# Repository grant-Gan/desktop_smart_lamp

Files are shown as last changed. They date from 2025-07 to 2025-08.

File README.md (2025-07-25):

# Sunlike 护眼台灯

使用首尔半导体Sunlike灯珠开发了一款具有无线控制和滑动控制双交互模式的台灯，结构灵活，可根据实际使用环境灵活调节灯管结构。控制器基于ESP32-C2模组，采用Arduino框架进行开发。  
版权说明：本项目允许用户查看、使用、修改源代码。禁止将项目或其衍生作品用于商业目的（例如：销售、作为商业服务的一部分盈利）。用户在使用或分发（包括修改版）时，必须保留原始版权和许可声明（注明出处）

<!-- PROJECT SHIELDS -->

[][contributors-url]
[][forks-url]
[][stars-url]
[][issues-url]
[][license-url]
[][linkedin-url]

<!-- PROJECT LOGO -->
<br />

<p align="center">
  <a href="https://github.com/grant-Gan/desktop_smart_lamp/">
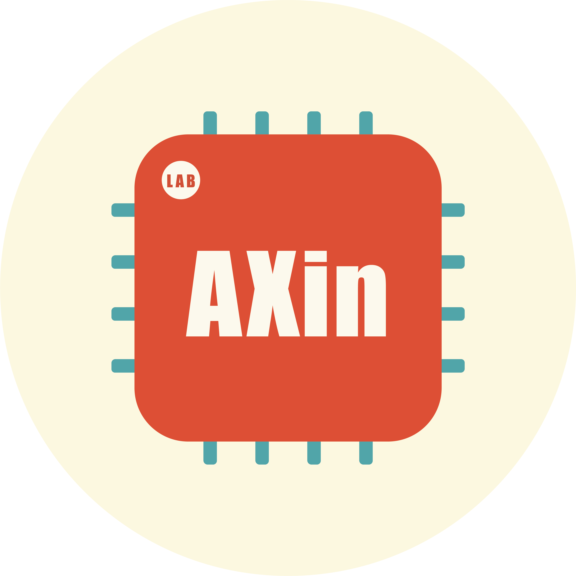
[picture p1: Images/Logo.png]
    
  </a>
  <h3 align="center">AXin实验室</h3>
  <p align="center">
    生命不息，折腾不止，Axin致力于DIY想要又买不起的产品~
    <br />
    <a href="https://github.com/grant-Gan/desktop_smart_lamp"><strong>探索本项目的文档 »</strong></a>
    <br />
    <br />
    <a href="https://github.com/grant-Gan/desktop_smart_lamp">查看Demo</a>
    ·
    <a href="https://github.com/grant-Gan/desktop_smart_lamp/issues">报告Bug</a>
    ·
    <a href="https://github.com/grant-Gan/desktop_smart_lamp/issues">提出新特性</a>
  </p>

</p>

## 目录

- [重点提示](#重点提示)
- [下载步骤](#下载步骤)
- [文件目录说明](#文件目录说明)
- [使用的框架](#使用的框架)
- [依赖库](#依赖库)
- [版本控制](#版本控制)
- [零件选型](#零件选型)
    1. [电源适配器](#电源适配器)
    2. [数据线](#数据线)
    3. [灯管](#灯管)
    4. [角码](#角码)
    5. [悬臂支架](#悬臂支架)
    6. [其它](#其它)
- [PCB焊接](#PCB焊接)
    1. [无线控制版本](#无线控制版本)
    2. [滑动控制版本](#滑动控制版本)
- [作者](#作者)
- [版权说明](#版权说明)

### 重点提示

截至到目前，台灯的旋转控制器代码仍然有Bug，AXin正在利用业余时间修复中，只能保证基础功能的正常使用。建议大家优先复刻滑动控制版本。

待开发功能：
1. 控制器Deep Sleep模式修复
2. 控制器与驱动板自动配对
3. 控制器低电提醒
4. HomeAssistant接入

### 下载步骤
Clone the repo

```sh
git clone https://github.com/grant-Gan/desktop_smart_lamp.git
```

### 文件目录说明

```
desktop_smart_lamp 
├── README.md
├── LICENSE
├── /3D_Model
│  ├── /Lamp_case
│  ├── /Rotary_Controller
│  ├── /Slider_Controller
├── /BOM
│  ├── /BOM_Base_Board_2025-07-23.xlsx
│  ├── /BOM_Driver Board _2025-07-23.xlsx
│  ├── /BOM_Rotary_Controller_Board_2025-07-23.xlsx
│  ├── /BOM_Slider_Controller_Board_2025-07-23.xlsx
├── /images
├── /Code
│  ├── /Lamp_Driver
│  ├── /Lamp_Driver
├── /PCBA
│  ├── /Gerber_Base_Board_20250723.zip
│  ├── /Gerber_Driver_Board_20250723.zip
│  ├── /Gerber_Rotary_Controller_Board_20250723.zip
│  ├── /Gerber_Slider_Controller_Board_20250723.zip
├── /Schematic
│  ├── /Base_board.pdf
│  ├── /Driver_board.pdf
│  ├── /Rotary_Controller_Board.pdf
│  ├── /Slider_Controller_board.pdf

```

### 使用的框架
[esp-idf](https://github.com/espressif/esp-idf) 

### 依赖库

- [arduino-esp32](https://github.com/espressif/arduino-esp32)
- [Button2](https://github.com/LennartHennigs/Button2)
- [ai-esp32-rotary-encoder](https://github.com/igorantolic/ai-esp32-rotary-encoder)

### 版本控制

该项目使用Git进行版本管理。您可以在repository参看当前可用版本。

### 零件选型
#### 电源适配器
本项目设计最大功耗为30W，输入电压为12~20V，20V时效率比较高，驱动板发热下降，推荐首选。因此需要使用额定30W以上、支持20V输出、支持PD充电协议的电源适配器，大部分手机配的快充头，如果功率大于30W，有TYPE-C接口都可以使用，不必额外购买。
<p align="center">
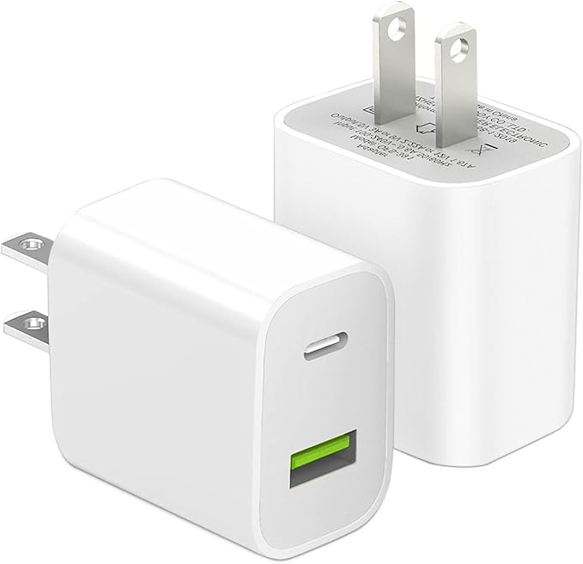
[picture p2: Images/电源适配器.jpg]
    
  <p align="center">有Type-C输出的电源适配器，通常支持PD协议</p>
</p>

#### 数据线
本项目使用的时C2C快充数据线，建议额定功率60W以上，长度根据使用环境选择，AXin使用的是2米的数据线，能够匹配大部分使用场景。
<p align="center">
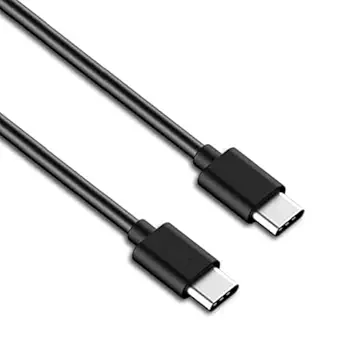
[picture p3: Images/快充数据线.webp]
    
  <p align="center">C2C快充数据线</p>
</p>

#### 灯管
本项目使用70cm长，横截面宽26mm，高11mm的铝合金灯管，购买地址见B站视频。商家默认出售的是1米长度，请留言需要裁剪。

#### 角码
本项目使用的是20*32*60的L型不锈钢角码，若想选用其他型号，需要保证螺丝孔开口大于6.0mm以上，能够让悬臂支架上1/4螺丝头伸进去。
<p align="center">
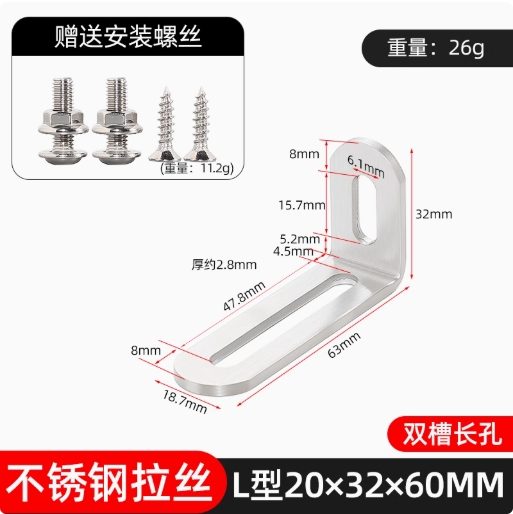
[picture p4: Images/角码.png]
    
  <p align="center">20x32x60角码</p>
</p>

#### 悬臂支架
本项目使用的是带有1/4螺丝的悬臂支架配合铝制夹具，需要注意的是由于灯管比较长，力臂较大，一定要选择质量足够好的悬臂支架才行，不然固定扳手的螺母会滑丝，建议大家不要贪图便宜，在正规渠道购买。
<p align="center">
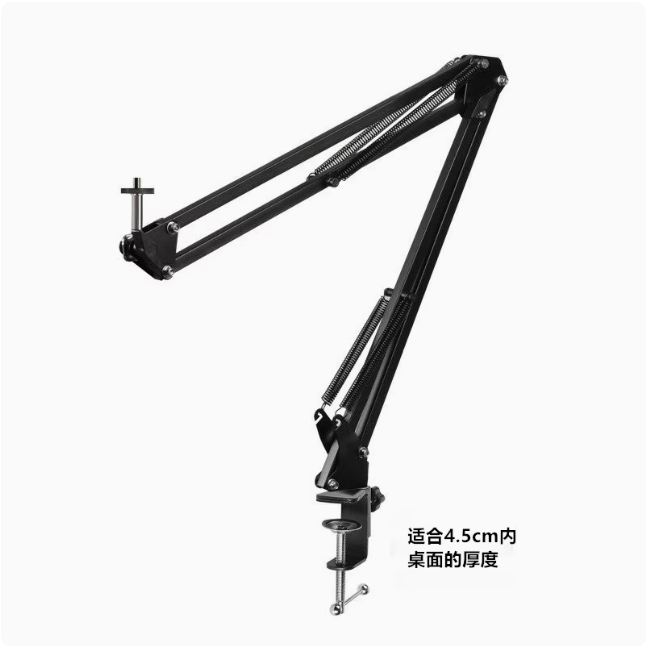
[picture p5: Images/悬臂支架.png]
    
  <p align="center">带1/4螺丝的悬臂支架</p>
</p>

#### 螺丝
- 无线控制版   

| 位置 | 型号 | 类型 | 螺丝头类型 | 数量 |
|---|---|---|---|----|
| 堵头与灯管连接 | M2.6*20 | 自攻螺丝 | 内六角 | 4  |
| 堵头上下连接  | M2*12 | 普通螺丝 | 内六角 | 2  |
| 堵头上下连接  | M2 | 螺母 | \ | 2  |
| 控制器 | M2*12 | 自攻螺丝 | 内六角 | 5  |
| 灯管与L角码连接 | M6*6 | 普通螺丝 | 内六角 | 2  |
| 灯管与L角码连接 | M6*10*2 | 方形螺母 | \ | 2  |
| L角码与支架连接 | 1/4-20牙 | 防滑螺母 | \ | 1  |
| L角码与支架连接 | M6*10*2 | 垫片 | \ | 1  |

- 滑动控制版

| 位置 | 型号 | 类型 | 螺丝头类型 | 数量 |
|---|---|---|---|----|
| 堵头与灯管连接  | M2.6*20 | 自攻螺丝 | 内六角 | 4  |
| 堵头与控制器连接 | M2*25 | 普通螺丝 | 内六角 | 2  |
| 堵头上下连接 | M2 | 螺母 | \ | 2  |
| 控制器与灯管连接 | M2*18 | 自攻螺丝 | 内六角 | 2  |
| 灯管与L角码连接 | M6*6 | 普通螺丝 | 内六角 | 2  |
| 灯管与L角码连接 | M6*10*2 | 方形螺母 | \ | 2  |
| L角码与支架连接 | 1/4-20牙 | 防滑螺母 | \ | 1  |
| L角码与支架连接 | M6*10*2 | 垫片 | \ | 1  |

#### 其它
其它零件暂时没有需要重点注意的，想起来或者等到后续问的朋友比较多再行补充~

### PCB焊接

#### 无线控制版本
- 驱动板  
无线控制驱动板使用ESP32-C2模组，使用PWM调光，驱动芯片为LGS63042EP,中间部分仅需要焊接R9、R18两个下拉电阻及D5、D6两个稳压二极管，其中稳压二极管用于保护驱动芯片EN引脚，可选。  
**注意事项：驱动端输出电压较高，需使用50V以上电容。**
<p align="center">
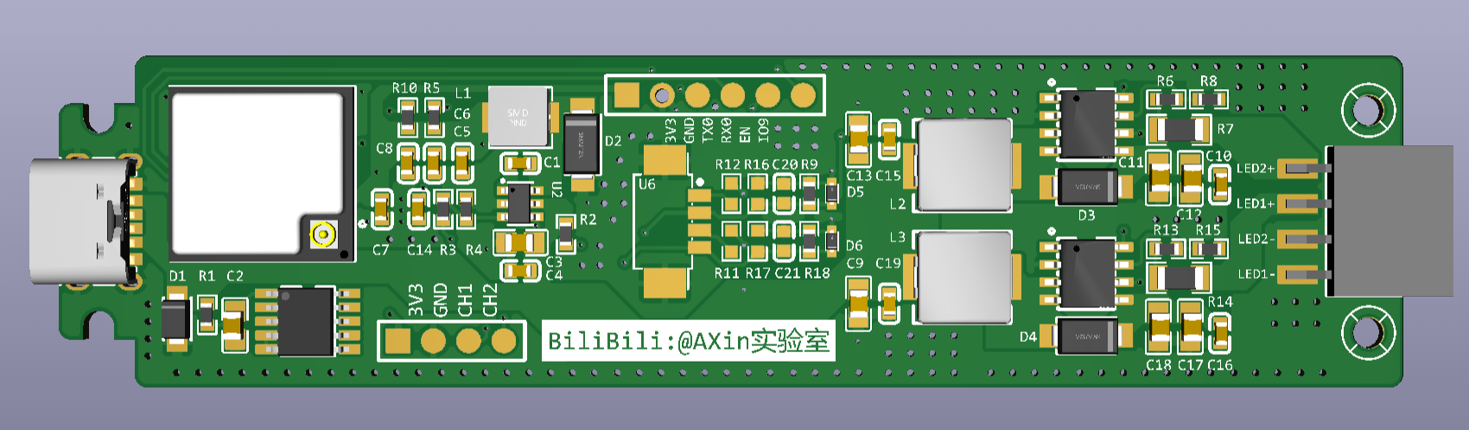
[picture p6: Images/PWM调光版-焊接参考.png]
    
无线控制版驱动板焊接参考 
</p>
  
- 控制板   
**注意事项：控制器焊接需要留意编码器的选型，本项目采用的编码器型号为EC11、手柄长度12mm、梅花柄、正码（顺时针）、旋转一圈脉冲20位**

<p align="center">
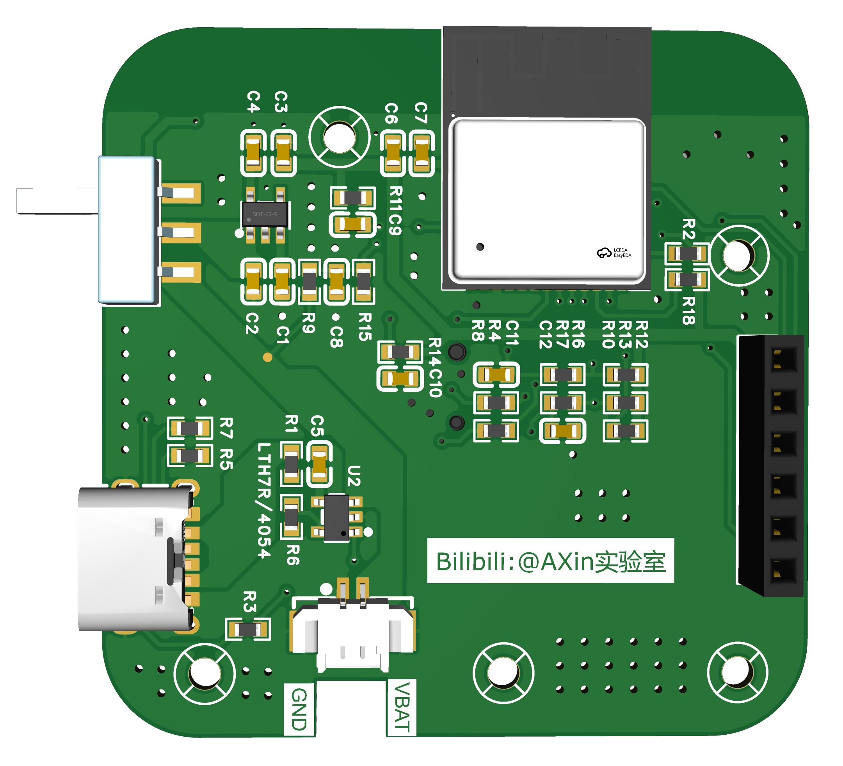
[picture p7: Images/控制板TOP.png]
  
  <p align="center">控制器焊接参考</p>
</p>

<p align="center">
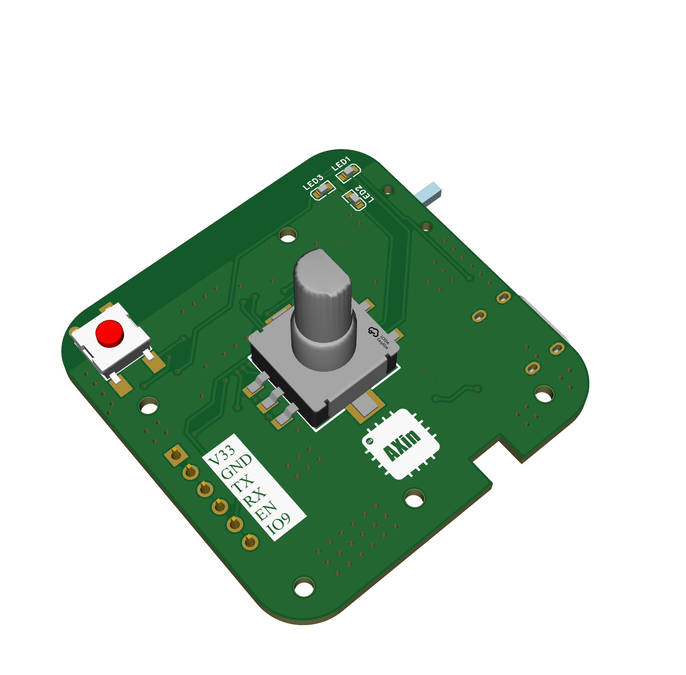
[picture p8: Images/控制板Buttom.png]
  
  <p align="center">控制器焊接参考</p>
</p>

#### 滑动控制版本
- 驱动板  
滑动控制版本可以不焊接控制器、DCDC部分的元器件，成本低不少，若没有无线控制需求，推荐给大家优先尝试。具体需要焊接的元件请参考下方的焊接参考图和原理图。
**注意事项：驱动端输出电压较高，需使用50V以上电容。**
<p align="center">
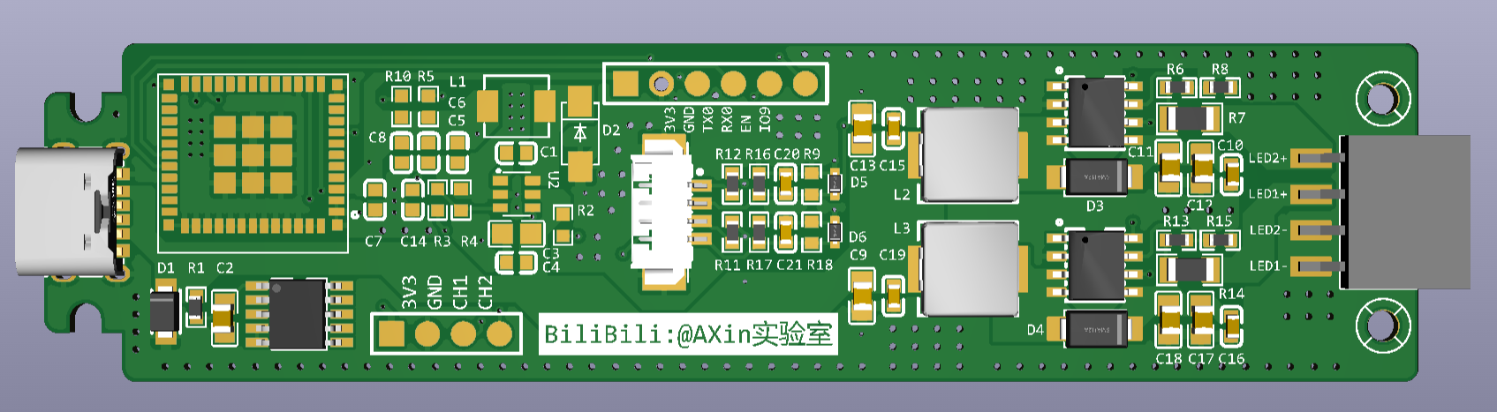
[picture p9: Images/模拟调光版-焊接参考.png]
    
滑动控制版驱动板焊接参考 
</p>  

- 滑动控制板  
这里没什么好说的，直接按照图焊接好就行。
<p align="center">
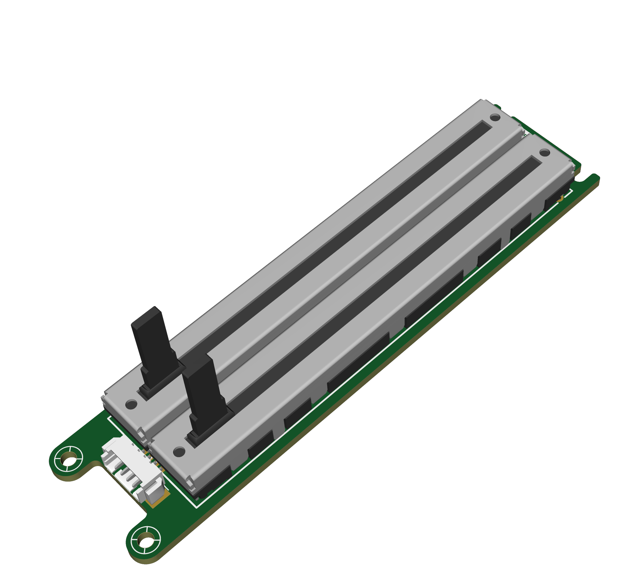
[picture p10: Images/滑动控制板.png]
    
  <p align="center">滑动控制板</p>
</p>  

### 作者

AXin实验室

Bilibili:@AXin实验室 小红书:@AXin实验室   

### 版权说明
本项目采用 **Creative Commons Attribution-NonCommercial-ShareAlike 4.0 International License** 授权。
您可自由地：
*   **共享** — 在任何媒介以任何形式复制、发行本作品
*   **演绎** — 修改、转换或以本作品为基础进行创作

惟须遵守以下条件：
*   **署名** — 您必须给出[适当的署名](https://creativecommons.org/licenses/by-nc-sa/4.0/deed.zh)，提供指向本许可协议的链接，同时标明是否（对原始作品）作了修改。您可以用任何合理的方式来署名，但不得以任何方式暗示许可人为您或您的使用背书。
*   **非商业性使用** — 您不得将本作品用于商业目的。
*   **相同方式共享** — 如果您再混合、转换或者基于本作品进行创作，您必须基于[与原先许可协议相同的许可协议](https://creativecommons.org/licenses/by-nc-sa/4.0/deed.zh) 分发您贡献的作品。

完整的许可条款请见：[LICENSE](LICENSE) 文件。

该项目签署了MIT 授权许可，详情请参阅 [LICENSE.txt](https://github.com/grant-Gan/desktop_smart_lamp/LICENSE.txt)

<!-- links -->
[your-project-path]:grant-Gan/desktop_smart_lamp
[contributors-shield]: https://img.shields.io/github/contributors/grant-Gan/desktop_smart_lamp.svg?style=flat-square
[contributors-url]: https://github.com/grant-Gan/desktop_smart_lamp/graphs/contributors
[forks-shield]: https://img.shields.io/github/forks/grant-Gan/desktop_smart_lamp.svg?style=flat-square
[forks-url]: https://github.com/grant-Gan/desktop_smart_lamp/network/members
[stars-shield]: https://img.shields.io/github/stars/grant-Gan/desktop_smart_lamp.svg?style=flat-square
[stars-url]: https://github.com/grant-Gan/desktop_smart_lamp/stargazers
[issues-shield]: https://img.shields.io/github/issues/grant-Gan/desktop_smart_lamp.svg?style=flat-square
[issues-url]: https://img.shields.io/github/issues/grant-Gan/desktop_smart_lamp.svg
[license-shield]: https://img.shields.io/github/license/grant-Gan/desktop_smart_lamp.svg?style=flat-square
[license-url]: https://github.com/grant-Gan/desktop_smart_lamp/blob/master/LICENSE.txt
[linkedin-shield]: https://img.shields.io/badge/-LinkedIn-black.svg?style=flat-square&logo=linkedin&colorB=555
[linkedin-url]: https://www.bilibili.com/video/BV1rygnzuE4w

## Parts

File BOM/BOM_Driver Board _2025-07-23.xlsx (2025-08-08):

No. | Manufacturer Part | Primary Category | Secondary Category | Manufacturer | LCSC Part Name | Footprint | Value | Designator | Quantity | Supplier Part
1 | CC0603KRX7R9BB104 |  |  | YAGEO(国巨) | 100nF ±10% 50V | C0603 | 100nF | C1,C4,C6,C8,C10,C13,C16,C19 | 8 | C14663
2 | HGC0805R5106K500NSLJ | 电容 | 贴片电容(MLCC) | Chinocera(华瓷) | 10uF ±10% 50V | C0805 | 10uF | C2,C3,C9,C11,C12,C15,C17,C18 | 8 | C22367830
3 | CGA0603X5R106K100JT |  |  | HRE(芯声) | 10uF ±10% 10V | C0603 | 10uF | C5,C7,C20,C21 | 4 | C6119842
4 | CGA0603X5R105K500JT |  |  | HRE(芯声) | 1uF ±10% 50V | C0603 | 1uF | C14 | 1 | C6119852
5 | SMF20A |  |  | 宏嘉诚 | SMF20A | SOD-123FL_L2.8-W1.9-LS3.7-RD |  | D1 | 1 | C41411782
6 | SS34 | 二极管 | 肖特基二极管 | 宏迦橙 | 电压:40V 电流:3A,电压:60V 电流:3A | SMA_L4.3-W2.6-LS5.0-FD |  | D2 | 3 | C7420365
6 | SS34,SS36 | 二极管 | 肖特基二极管 | 宏迦橙 | 电压:60V 电流:3A,电压:60V 电流:3A | SMA_L4.3-W2.6-LS5.0-FD |  | D3,D4 | 3 | C7420367
7 | BZX584C5V1 |  |  | 宏迦橙 | BZX584C5V1 | SOD-523_L1.2-W0.8-LS1.6-FD |  | D5,D6 | 2 | C19077463
8 | FXL0420-100-M |  |  | cjiang(长江微电) | 10uH ±20% 2.2A | IND-SMD_L4.4-W4.2 | 10uH | L1 | 1 | C177242
9 | FXL0630-4R7-M |  |  | cjiang(长江微电) | 4.7uH ±20% 9A | IND-SMD_L7.0-W6.6 | 4.7uH | L2,L3 | 2 | C167220
10 |  | Connector | 2.54mm |  |  | 卧贴排母 2.54mm 4P |  | P1 | 1
11 | 0603WAJ0102T5E |  |  | UNI-ROYAL(厚声) | 1kΩ ±5% 100mW 厚膜电阻 | R0603 | 1kΩ | R1 | 1 | C25585
12 | 0603WAJ0103T5E |  |  | UNI-ROYAL(厚声) | 10kΩ ±5% 100mW 厚膜电阻 | R0603 | 10kΩ | R2,R5,R9,R10,R18 | 5 | C15401
13 | FRC0603F1302TS | 电阻 | 贴片电阻 | FOJAN(富捷) | 13kΩ ±1% 100mW 厚膜电阻 | R0603 | 13kΩ | R3 | 1 | C2906992
14 | FRC0603F4301TS | 电阻 | 贴片电阻 | FOJAN(富捷) | 4.3kΩ ±1% 100mW 厚膜电阻 | R0603 | 4.3kΩ | R4 | 1 | C2930099
15 | 0603WAF2003T5E |  |  | UNI-ROYAL(厚声) | 200kΩ ±1% 100mW 厚膜电阻 | R0603 | 200kΩ | R6,R13 | 2 | C25811
16 | 1206W4F500LT5E |  |  | UNI-ROYAL(厚声) | 500mΩ ±1% 250mW 厚膜电阻 | R1206 | 500mΩ | R7,R14 | 2 | C25340
17 | RC0603FR-074K7L |  |  | YAGEO(国巨) | 厚膜电阻 4.7kΩ ±1% 100mW | R0603 | 4.7kΩ | R8,R15 | 2 | C99782
18 | 0603WAF9101T5E |  |  | UNI-ROYAL(厚声) | 9.1kΩ ±1% 100mW 厚膜电阻 | R0603 | 9.1kΩ | R11,R12 | 2 | C23260
19 | 0603WAF5100T5E |  |  | UNI-ROYAL(厚声) | 510Ω ±1% 100mW 厚膜电阻 | R0603 | 510Ω | R16,R17 | 2 | C23193
20 |  |  |  |  |  | M2螺丝 |  | SCREW1,SCREW2 | 2
21 | CH224K | 通信接口芯片/UART/485/232 | USB芯片 | WCH(南京沁恒) | USB PD等多快充协议受电芯片CH224 | ESSOP-10_L4.9-W3.9-P1.0-LS6.0-TL-EP |  | U1 | 1 | C970725
22 | LGS5145 | 电源管理 | DC-DC电源芯片 | Legend-Si(棱晶半导体) | 高效率异步降压转换器 | SOT-23-6_L2.9-W1.7-P0.95-LS2.8-BL |  | U2 | 1 | C5123971
23 | ESP8684-MINI-1U-H4 | 物联网/通信模块 | 蓝牙模块 | ESPRESSIF(乐鑫) | ESP8684-MINI-1U-H4 | WIFIM-SMD_61P-L13.2-W12.5-P0.80 |  | U3 | 1 | C7497295
24 | LGS63042EP | 数码管驱动/LED驱动 | LED驱动 | Legend-Si(棱晶半导体) | 输出1.2A PWM调光 降压,升压型驱动 | ESOP-8_L4.9-W3.9-P1.27-LS6.0-TL-EP3.3 |  | U4,U5 | 2 | C5280696
25 | ZX-MX1.25-4PWT | 连接器 | 线对板针座 | Megastar(兆星) | 1x4P 间距:1.25mm 卧贴 系列:PicoBlade(MX 1.25) 配套胶壳型号：ZX-MX1.25-4PJK 配套端子型号：ZX-MX1.25-DZ 配套杜邦线型号：ZX-MX1.25-4PBXC | CONN-SMD_4P-P1.25-MX1.25-4P-WT |  | U6 | 1 | C7430470
26 | TYPE-C 6P(073) |  |  | SHOU HAN(首韩) | Type-C 母 卧贴 | TYPE-C-SMD_TYPE-C-6P-073 |  | USB1 | 1 | C668623

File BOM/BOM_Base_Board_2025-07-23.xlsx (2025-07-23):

No. | Manufacturer Part | Primary Category | Secondary Category | Manufacturer | Footprint | Value | Designator | Quantity
1 | STW9C2SB-S | 光电器件 | 发光二极管/LED | 首尔半导体 | LED-SMD_L3.0-W3.0_XL-3030UWC-1W-6V | 2700K, 6V, 1W, 150mA | LED7,LED8,LED9,LED10,LED11 | 5
1 | STW9C2SB-S | 光电器件 | 发光二极管/LED | 首尔半导体 | LED-SMD_L3.0-W3.0_XL-3030UWC-1W-6V | 5000K, 6V, 1W, 150mA | LED1,LED2,LED3,LED4,LED5 | 5
2 |  | Connector | 2.54mm |  | 卧贴排母 2.54mm 4P |  | P1 | 1
3 |  | Connector | 2.54mm |  | 卧贴排针 2.54mm 4P |  | P2 | 1

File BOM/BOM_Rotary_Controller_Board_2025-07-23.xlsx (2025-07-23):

No. | Manufacturer Part | Primary Category | Secondary Category | Manufacturer | LCSC Part Name | Footprint | Value | Designator | Quantity | Supplier Part
1 | CGA0603X5R106K100JT |  |  | HRE(芯声) | 10uF ±10% 10V | C0603 | 10uF | C1,C3,C5,C6,C9 | 5 | C6119842
2 | CGA0603X7R104K500JT |  |  | HRE(芯声) | 100nF ±10% 50V | C0603 | 100nF | C2,C4,C7,C8 | 4 | C6119867
3 | CC0603KRX7R9BB103 |  |  | YAGEO(国巨) | 10nF ±10% 50V | C0603 | 10nF | C10,C11,C12 | 3 | C100042
4 | 2.54-1*6P母 | 连接器 | 排母 | BOOMELE(博穆精密) |  | HDR-TH_6P-P2.54-V-F |  | H1 | 1 | C40877
5 | ME6211C33M5G-N | 电源管理 | 线性稳压器(LDO) | MICRONE(南京微盟) | 输入6V 输出3.3V 500mA | SOT-23-5_L3.0-W1.7-P0.95-LS2.8-BL |  | LDO1 | 1 | C82942
6 | XL-1608UWC-04 |  |  | XINGLIGHT(成兴光) | XL-1608UWC-04 | LED0603-RD_WHITE |  | LED1,LED2,LED3 | 3 | C965808
7 | FRL0603JR500TS |  |  | FOJAN(富捷) | 500mΩ ±5% 100mW 厚膜电阻 | R0603 | 500mΩ | R1 | 1 | C2930046
8 | 0603WAF4701T5E |  |  | UNI-ROYAL(厚声) | 4.7kΩ ±1% 100mW 厚膜电阻 | R0603 | 4.7kΩ | R2,R3,R4,R8 | 4 | C23162
9 | 0603WAF5101T5E |  |  | UNI-ROYAL(厚声) | 5.1kΩ ±1% 100mW 厚膜电阻 | R0603 | 5.1kΩ | R5,R7 | 2 | C23186
10 | 0603WAF2402T5E |  |  | UNI-ROYAL(厚声) | 24kΩ ±1% 100mW 厚膜电阻 | R0603 | 24kΩ | R6 | 1 | C23352
11 | 0603WAJ0102T5E |  |  | UNI-ROYAL(厚声) | 1kΩ ±5% 100mW 厚膜电阻 | R0603 | 1kΩ | R9 | 1 | C25585
12 | 0603WAJ0103T5E |  |  | UNI-ROYAL(厚声) | 10kΩ ±5% 100mW 厚膜电阻 | R0603 | 10kΩ | R10,R11,R12,R13,R14,R15,R16,R17,R18 | 9 | C15401
13 |  |  |  |  |  | M2螺丝 |  | SCREW1,SCREW2,SCREW3,SCREW4,SCREW5 | 5
14 | KH-6X6X7H-STM | 按键/开关 | 轻触开关 | kinghelm(金航标) | 6*6*7mm 立贴 轻触开关 | SW-SMD_4P-L6.0-W6.0-P4.50-LS9.0-2 |  | SW1 | 1 | C2837533
15 | EC11E09244BS | 按键/开关 | 旋转编码器 | ALPSALPINE(阿尔卑斯阿尔派) | EC11E09244BS | SW-SMD_EC11 |  | SW2 | 1 | C470742
16 |  |  |  |  |  | Test-Point-0.5mm |  | TP1 | 1
17 |  |  |  |  |  | MSKT-12D14 |  | U1 | 1
18 | LTH7R/4054 | 电源管理 | 电池管理 | FM(富满) | LTH7R/4054 | SOT-23-5_L2.9-W1.6-P0.95-LS2.8-BR |  | U2 | 1 | C2913899
19 | ZX-MX1.25-2PWT | 连接器 | 线对板针座 | Megastar(兆星) | 1x2P 间距:1.25mm 卧贴 系列:PicoBlade(MX 1.25) 配套胶壳型号：ZX-MX1.25-2PJK 配套端子型号：ZX-MX1.25-DZ 配套杜邦线型号：ZX-MX1.25-2PBXC | CONN-SMD_2P-P1.25_MEGASTAR_ZX-MX1.25-2PWT |  | U3 | 1 | C7430468
20 | ESP8684-MINI-1-H2 | 物联网/通信模块 | WiFi模块 | ESPRESSIF(乐鑫) | ESP8684-MINI-1-H2 | WIFI-SMD_ESP8684-MINI-1 |  | U4 | 1 | C3013915
21 | TYPE-C 6P(073) |  |  | SHOU HAN(首韩) | Type-C 母 卧贴 | TYPE-C-SMD_TYPE-C-6P_5 |  | USB1 | 1 | C668623

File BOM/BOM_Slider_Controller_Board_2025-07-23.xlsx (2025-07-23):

No. | Manufacturer Part | Primary Category | Secondary Category | Manufacturer | LCSC Part Name | Footprint | Value | Designator | Quantity | Supplier Part
1 | RS6011DP6003 | 电阻 | 可调电阻/电位器 | ALPSALPINE(阿尔卑斯阿尔派) | 10kΩ ±20%,20kΩ ±20% | RES-ADJ-TH_L75.0-W9.0_RS60112A6A0C | 10kΩ | R13,R14 | 2
2 |  |  |  |  |  | M2螺丝 |  | SCREW1,SCREW2,SCREW3,SCREW4 | 4
3 | ZX-MX1.25-4PWT | 连接器 | 线对板针座 | Megastar(兆星) | 1x4P 间距:1.25mm 卧贴 系列:PicoBlade(MX 1.25) 配套胶壳型号：ZX-MX1.25-4PJK 配套端子型号：ZX-MX1.25-DZ 配套杜邦线型号：ZX-MX1.25-4PBXC | CONN-SMD_4P-P1.25-MX1.25-4P-WT |  | U6 | 1 | C7430470

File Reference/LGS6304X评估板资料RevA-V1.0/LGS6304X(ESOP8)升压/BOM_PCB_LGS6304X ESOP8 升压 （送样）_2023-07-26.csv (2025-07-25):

ID | Name | Designator | Footprint | Quantity | Manufacturer Part | Manufacturer | Supplier | Supplier Part | Price
1 | 10uF | C3,C2 | C0805 | 2 | C1210C106K5RAC7800 | KEMET | LCSC | C141222 | 2.83
2 | TP1502 | EN,LED+,VIIN,GND | TEST POINT -2 | 4 | Header-Male-2.54_1x1 | ReliaPro | LCSC | C81276 | 0.0413
3 | 4.7uF | C1 | C1210 | 1 | C1210C106K5RAC7800 | KEMET | LCSC | C141222 | 2.83
4 | PMEG6020ER,115 | D1 | SOD-123_L2.8-W1.8-LS3.7-RD | 1 | PMEG6020ER,115 | Nexperia | LCSC | C98663 | 0.9184
5 | 1 | R6 | R0805 | 1 | 0805W8F100KT5E | UNI-ROYAL(厚声) | LCSC | C25271 | 0.0172
6 | 4.7uH | L1 | IND-SMD_L5.4-W5.2 | 1 | MWSA0503-100MT | Sunlord | LCSC | C139506 | 1.1875
7 | 470k | R3 | R0603 | 1 |  |  |  | C23178 | 0.0064
8 | 10k | R4,R1 | R0603 | 2 |  |  |  | C25804 | 0.0055
9 | 10K | R2 | R0603 | 1 |  |  |  | C13167 | 0.0064

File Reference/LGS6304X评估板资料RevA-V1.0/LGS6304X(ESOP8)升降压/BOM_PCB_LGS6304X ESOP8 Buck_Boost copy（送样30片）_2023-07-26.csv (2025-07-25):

ID | Name | Designator | Footprint | Quantity | Manufacturer Part | Manufacturer | Supplier | Supplier Part | Price
1 | 10uF | C2 | C0805 | 1 | C1210C106K5RAC7800 | KEMET | LCSC | C141222 | 2.83
2 | 10uF | C1 | C1210 | 1 | C1210C106K5RAC7800 | KEMET | LCSC | C141222 | 2.83
3 | PMEG6020ER,115 | D1 | SOD-123_L2.8-W1.8-LS3.7-RD | 1 | PMEG6020ER,115 | Nexperia | LCSC | C98663 | 0.9184
4 | 10uH | L1 | IND-SMD_L5.4-W5.2 | 1 | MWSA0503-100MT | Sunlord | LCSC | C139506 | 1.1875
5 | 10k | R1,R2,R4 | R0603 | 3 |  |  |  | C25804 | 0.0055
6 | 680k | R3 | R0603 | 1 |  |  |  | C25822 | 0.0062
7 | 0.5Ω | RSENCE | R0805 | 1 |  |  |  | C28319 | 0.0265
8 | LGS6304X SOP | U1 | ESOP8-5500 | 1 |  |  | LCSC | C5280696 | 0.7483
9 | TP1502 | VIIN,EN,LED+,LED- | TEST POINT -2 | 4 | Header-Male-2.54_1x1 | ReliaPro | LCSC | C81276 | 0.0413

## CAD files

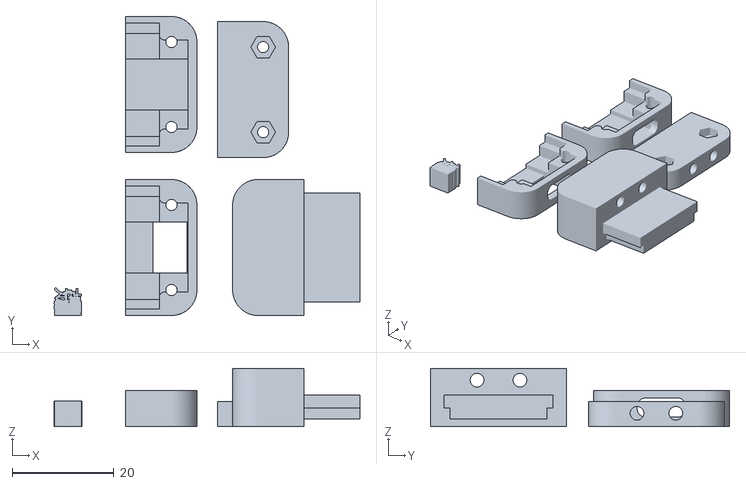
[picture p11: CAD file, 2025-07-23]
3D_Model/Lamp_case/两侧堵头.stl
60.1 x 58.7 x 11.4

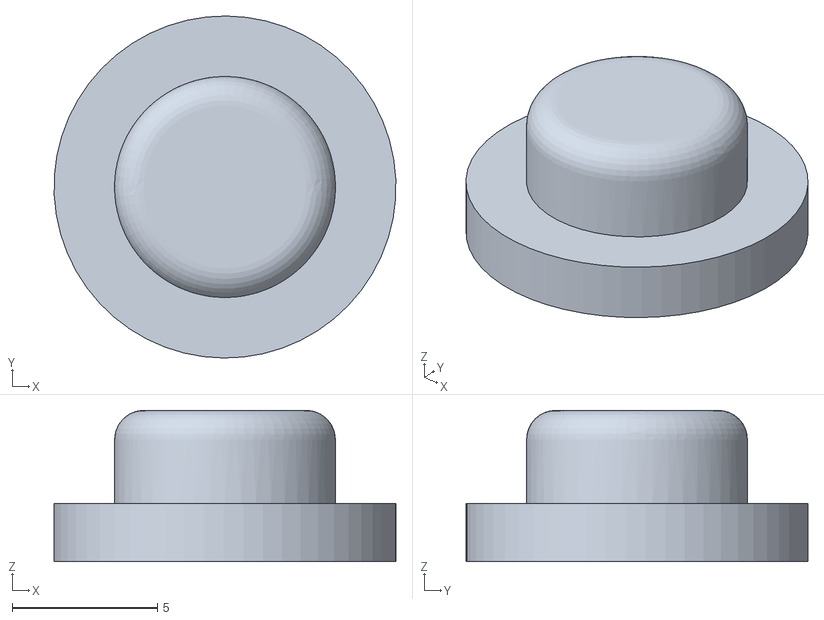
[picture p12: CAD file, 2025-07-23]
3D_Model/Rotary_Controller/按键.stl
11.8 x 11.8 x 5.20

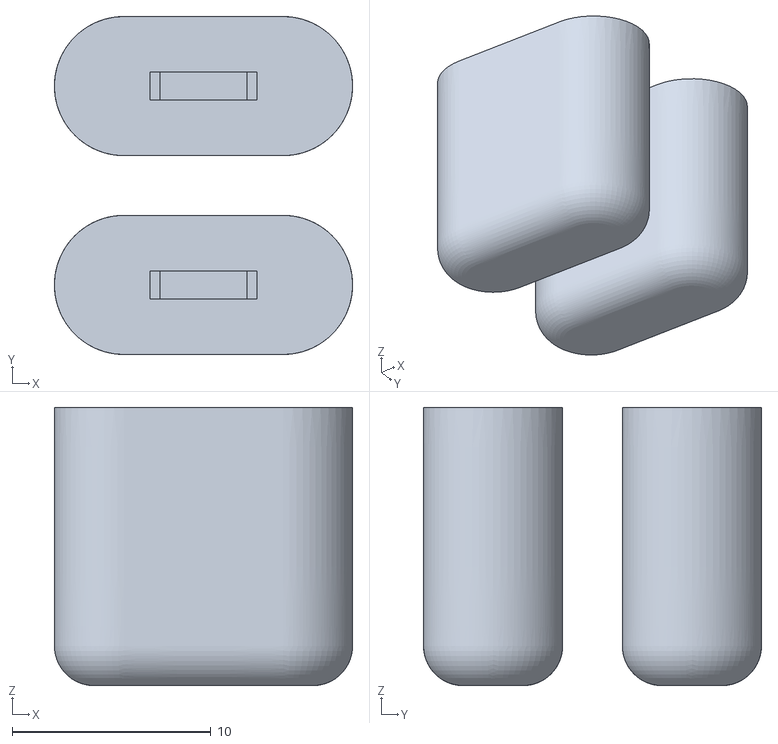
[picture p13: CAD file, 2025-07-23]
3D_Model/Slider_Controller/手柄.stl
15.0 x 17.0 x 14.0

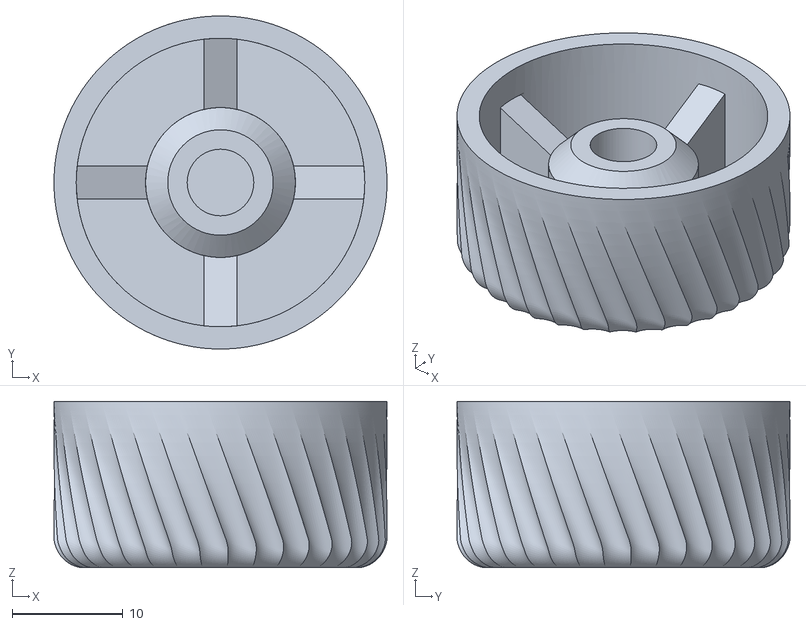
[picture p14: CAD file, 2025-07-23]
3D_Model/Rotary_Controller/旋钮.stl
30.0 x 30.0 x 15.0

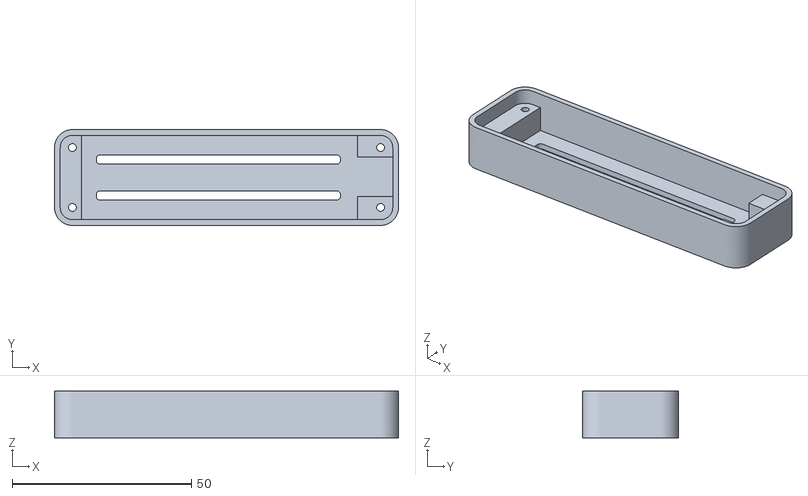
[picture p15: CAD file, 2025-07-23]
3D_Model/Slider_Controller/外壳.stl
95.9 x 26.7 x 13.0

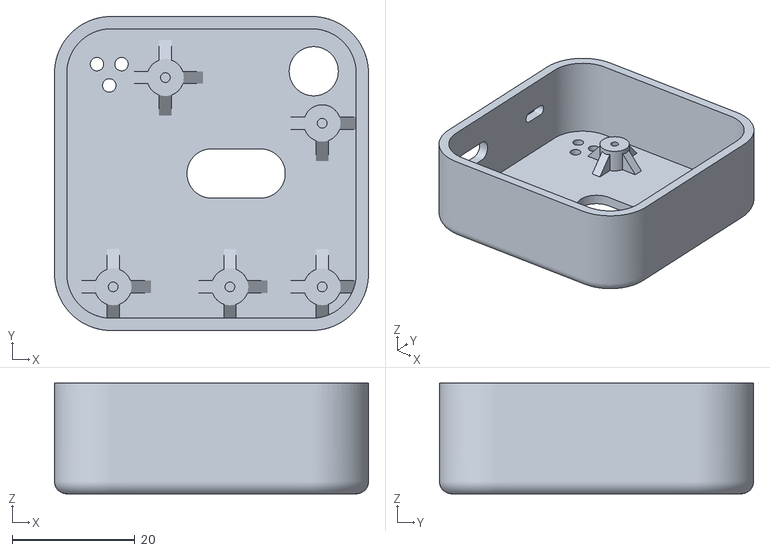
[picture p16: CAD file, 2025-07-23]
3D_Model/Rotary_Controller/外壳.stl
51.1 x 51.1 x 18.0

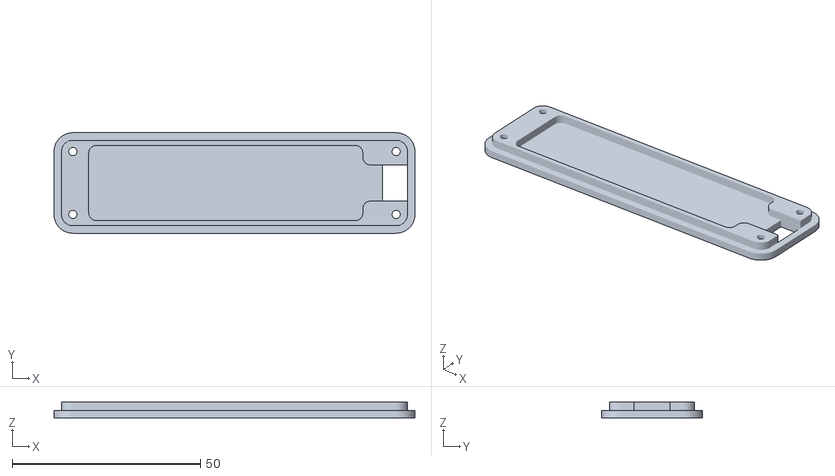
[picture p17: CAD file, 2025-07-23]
3D_Model/Slider_Controller/外壳盖.stl
95.9 x 26.7 x 4.20

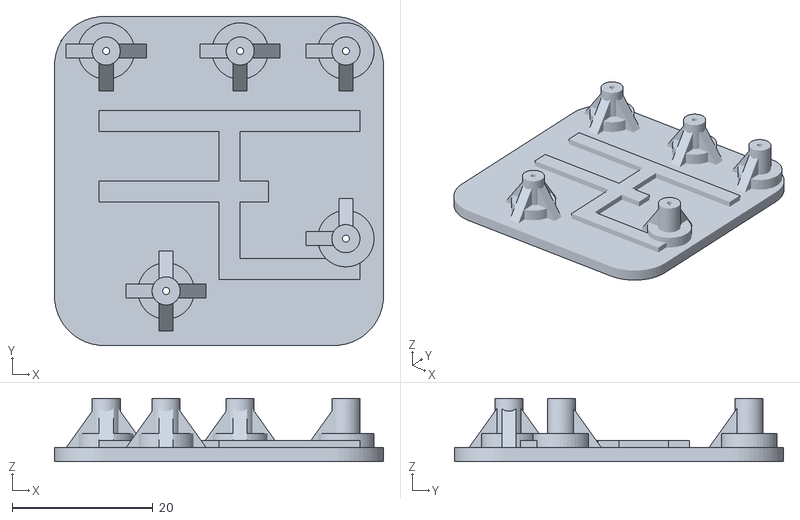
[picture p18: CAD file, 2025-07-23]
3D_Model/Rotary_Controller/底板.stl
46.7 x 46.7 x 9.00

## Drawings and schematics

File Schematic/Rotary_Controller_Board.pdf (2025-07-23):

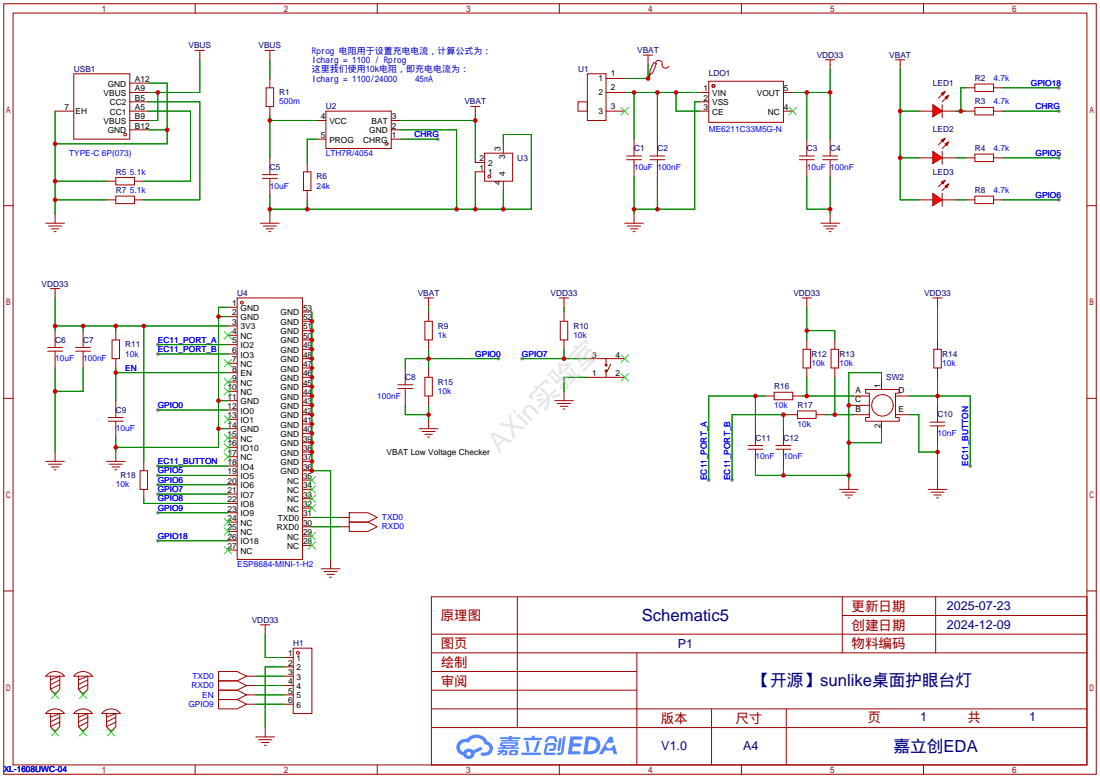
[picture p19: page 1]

VBAT Low Voltage Checker

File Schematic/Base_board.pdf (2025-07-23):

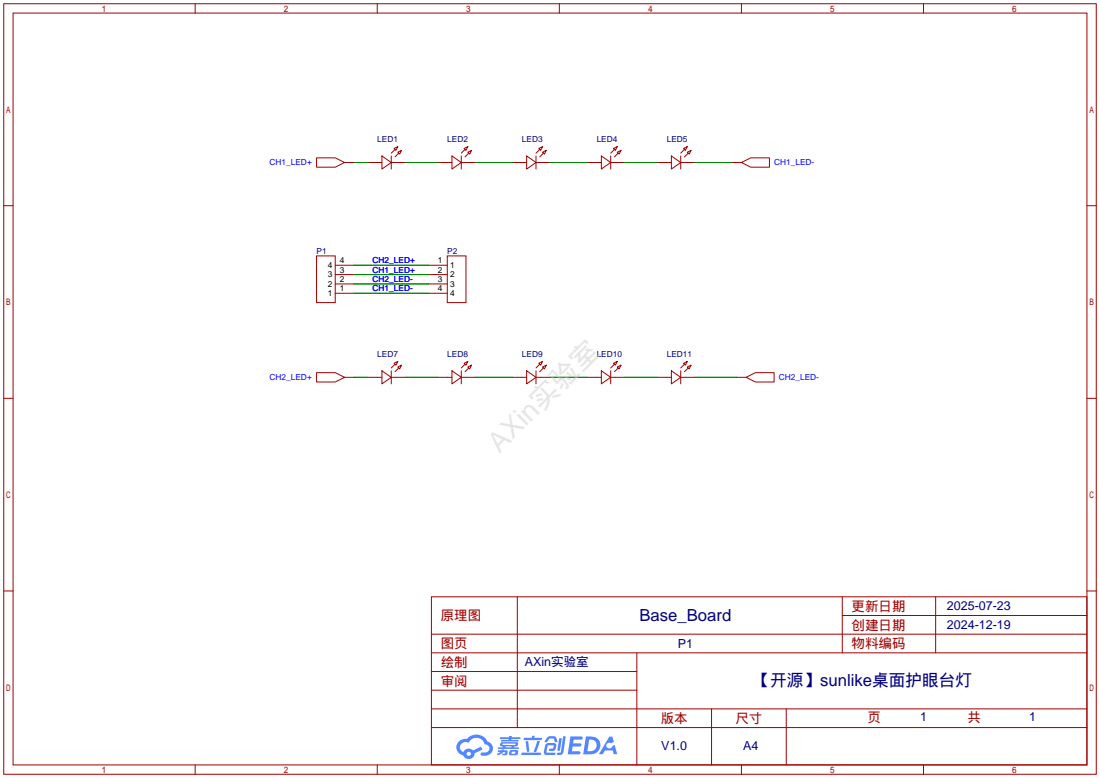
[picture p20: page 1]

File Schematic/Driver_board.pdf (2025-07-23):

## 使用模拟调光时，此电路不接

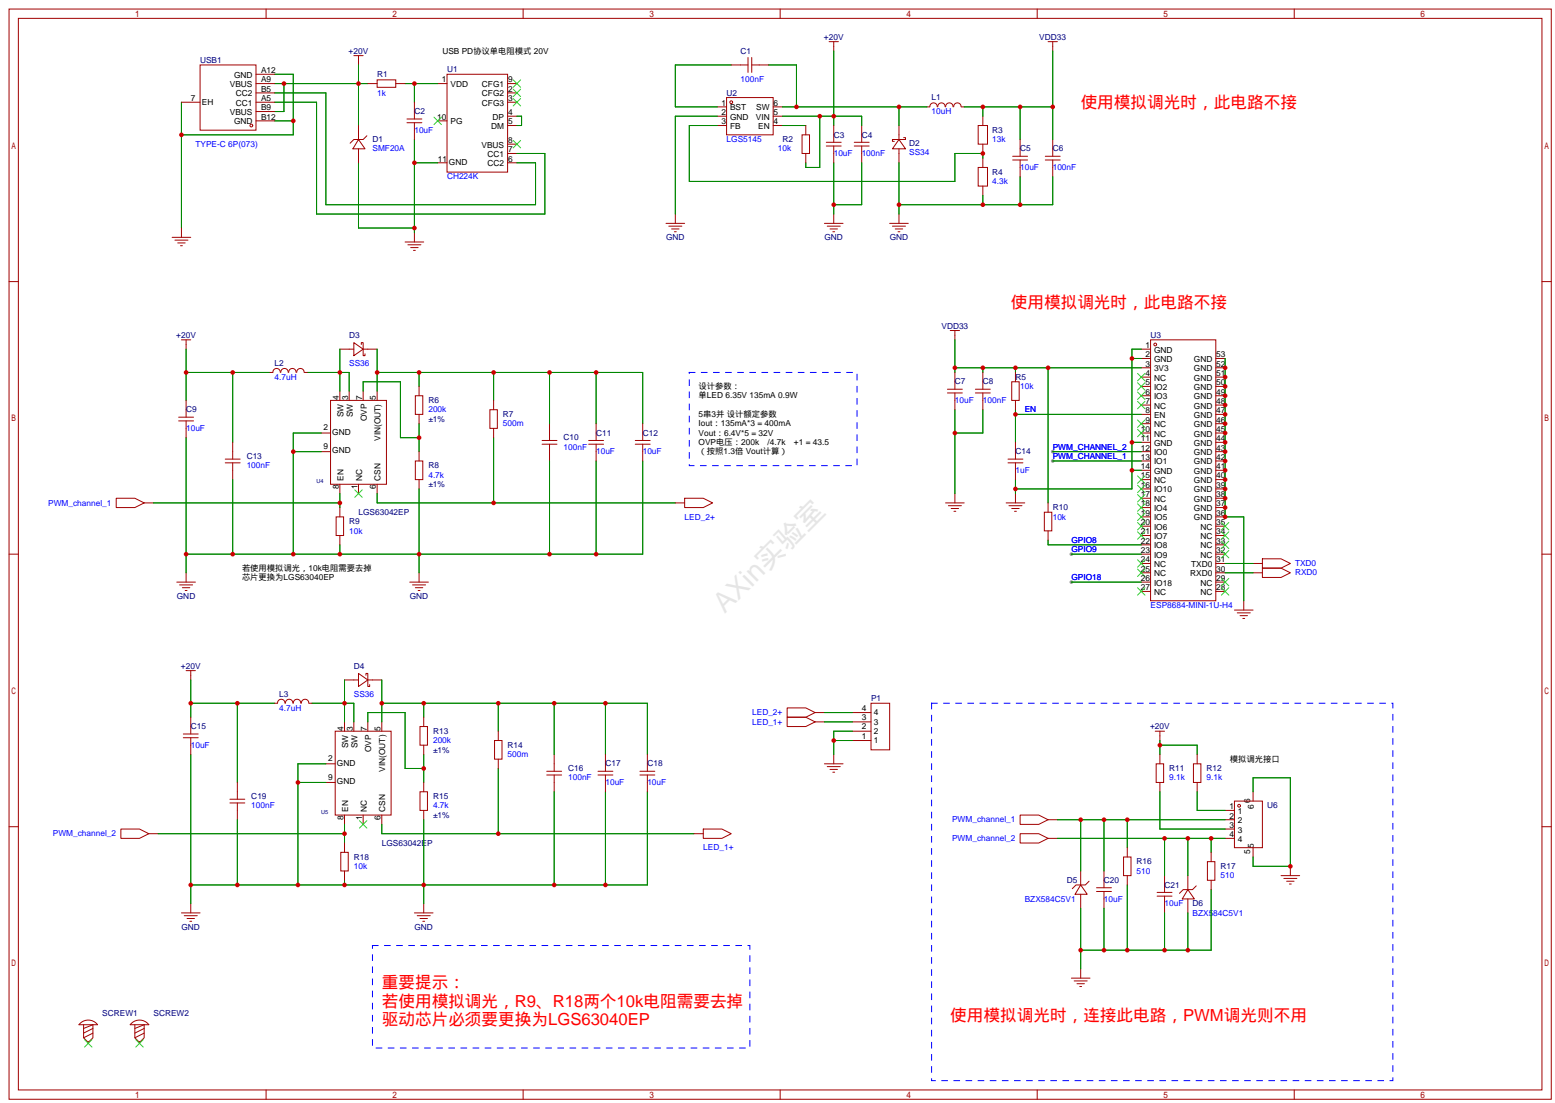
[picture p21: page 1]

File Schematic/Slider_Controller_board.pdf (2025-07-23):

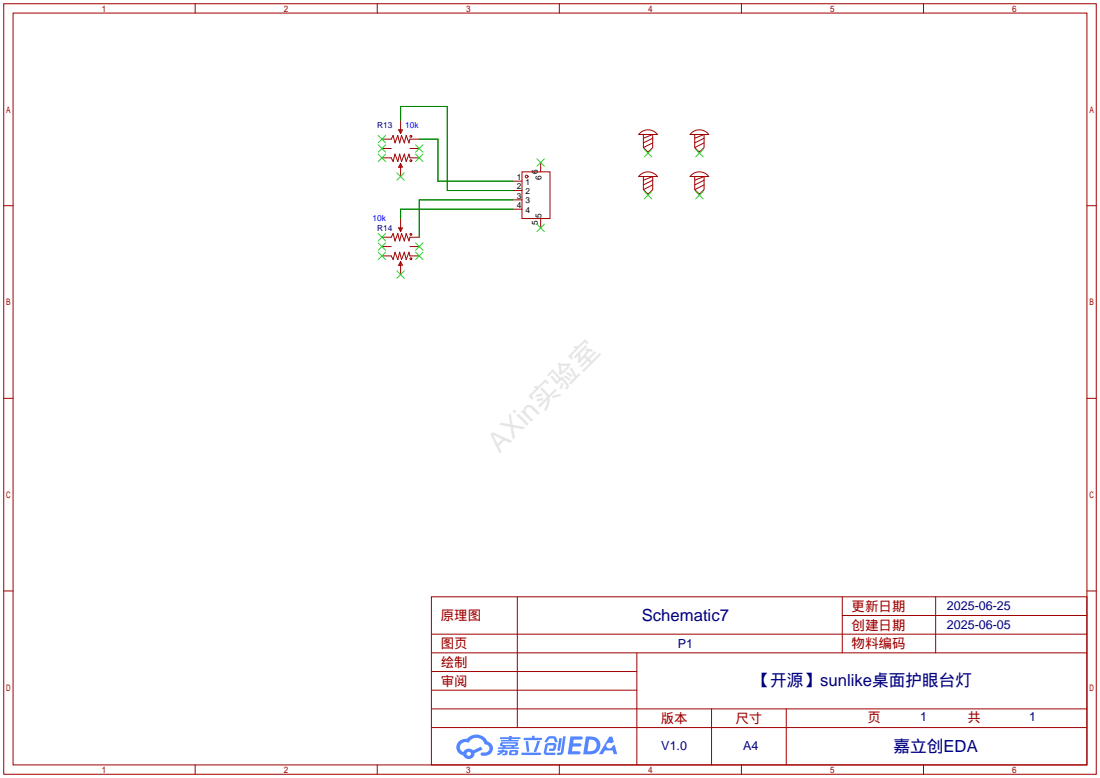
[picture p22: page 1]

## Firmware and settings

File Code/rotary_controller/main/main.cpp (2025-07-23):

/*
ledc arduino: https://docs.espressif.com/projects/arduino-esp32/en/latest/api/ledc.html
led rtc config: https://www.espressif.com/sites/default/files/documentation/esp8684_technical_reference_manual_cn.pdf#ledpwm
*/

#include "Arduino.h"
#include "main.hpp"

Preferences preference;
Button2 encoderButton(ENCODER_BUTTON_PIN);

/*****************LED Controller*******************/

const uint16_t MAX_DUTY = pow(2, PWM_RES) - 1; // Max num: 511
const uint16_t MINIMUM_DUTY = 0;
const uint16_t MAX_TEMPERATURE = MAX_DUTY; // 511

struct user_lamp_info_t
{
    int32_t current_duty_ch[2] = {0};
    int32_t target_duty_ch[2] = {0};
    float led_temperature = 0.5f;
} user_lamp_info;

struct_message send_data{
    .msgType = DATA,
    .id = BOARD_ID,
    .command = SET_DUTY,
    .data = {0, 0}};

void readGetMacAddress()
{
    uint8_t baseMac[6];
    esp_err_t ret = esp_wifi_get_mac(WIFI_IF_STA, baseMac);
    if (ret == ESP_OK)
    {
        Serial.printf("%02x:%02x:%02x:%02x:%02x:%02x\n",
                      baseMac[0], baseMac[1], baseMac[2],
                      baseMac[3], baseMac[4], baseMac[5]);
    }
    else
    {
        Serial.println("Failed to read MAC address");
    }
    clientMacAddress[0] = baseMac[0];
    clientMacAddress[1] = baseMac[1];
    clientMacAddress[2] = baseMac[2];
    clientMacAddress[3] = baseMac[3];
    clientMacAddress[4] = baseMac[4];
    clientMacAddress[5] = baseMac[5];
}

void addPeer(const uint8_t *mac_addr, uint8_t chan)
{
    ESP_ERROR_CHECK(esp_wifi_set_channel(chan, WIFI_SECOND_CHAN_NONE));
    esp_now_del_peer(mac_addr);
    memset(&peer_info, 0, sizeof(esp_now_peer_info_t));
    peer_info.channel = chan;
    peer_info.encrypt = false;
    memcpy(peer_info.peer_addr, mac_addr, sizeof(uint8_t[6]));
    if (esp_now_add_peer(&peer_info) != ESP_OK)
    {
        Serial.println("Failed to add peer");
        return;
    }
    memcpy(serverAddress, mac_addr, sizeof(uint8_t[6]));
}

void printMAC(const uint8_t *mac_addr)
{
    char macStr[18];
    snprintf(macStr, sizeof(macStr), "%02x:%02x:%02x:%02x:%02x:%02x",
             mac_addr[0], mac_addr[1], mac_addr[2], mac_addr[3], mac_addr[4], mac_addr[5]);
    Serial.print(macStr);
}

void OnDataSent(const uint8_t *mac_addr, esp_now_send_status_t status)
{
    Serial.print("\r\nLast Packet Send Status:\t");
    Serial.println(status == ESP_NOW_SEND_SUCCESS ? "Delivery Success" : "Delivery Fail");
    // if (status != ESP_NOW_SEND_SUCCESS && pairingStatus == PAIR_PAIRED)
    // {
    //     pairingStatus = PAIR_REQUEST;
    // }
}

void OnDataRecv(const uint8_t *mac_addr, const uint8_t *incomingData, int len)
{
    Serial.print("Packet received with ");
    Serial.print("data size = ");
    Serial.println(sizeof(incomingData));
    uint8_t type = incomingData[0];
    switch (type)
    {
    case DATA: // we received data from server
        memcpy(&inData, incomingData, sizeof(inData));
        if (inData.command == SET_DUTY)
        {
            user_lamp_info.current_duty_ch[0] = inData.data[0];
            user_lamp_info.current_duty_ch[1] = inData.data[1];
            if (inData.data[0] + inData.data[1] == 0)
            {
                ledState = LED_POWER_OFF;
            }
            else
            {
                ledState = LED_POWER_ON;
            }
        }
        else if (inData.command == POWER_OFF)
        {
            ledState = LED_POWER_OFF;
        }
        break;

    case PAIRING: // we received pairing data from server
        memcpy(&pairingData, incomingData, sizeof(pairingData));
        if (pairingData.id == 0)
        { // the message comes from server
            Serial.print("Pairing done for MAC Address: ");
            printMAC(pairingData.macAddr);
            Serial.print(" on channel ");
            Serial.print(pairingData.channel); // channel used by the server
            Serial.print(" in ");
            Serial.print(millis() - start_time);
            Serial.println("ms");
            addPeer(pairingData.macAddr, pairingData.channel); // add the server  to the peer list

            pairingStatus = PAIR_PAIRED; // set the pairing status
            saveMyPreference("my_preference", "peer_info", &peer_info, sizeof(esp_now_peer_info_t));
        }
        break;
    }
}

PairingStatus autoPairing()
{
    switch (pairingStatus)
    {
    case HAVE_RECORD:
        Serial.print("ESP NOW have paring record: ");
        printMAC(peer_info.peer_addr);
        Serial.printf("  channel is: %d \n", peer_info.channel);

        // set WiFi channel
        ESP_ERROR_CHECK(esp_wifi_set_channel(peer_info.channel, WIFI_SECOND_CHAN_NONE));
        if (esp_now_init() != ESP_OK)
        {
            Serial.println("Error initializing ESP-NOW");
        }

        // set callback routines
        esp_now_register_send_cb(OnDataSent);
        esp_now_register_recv_cb(esp_now_recv_cb_t(OnDataRecv));

        if (esp_now_add_peer(&peer_info) != ESP_OK)
        {
            Serial.println("Failed to add peer");
            pairingStatus = PAIR_REQUEST;
            break;
        }
        Serial.println("ESP NOW init sucessfully from NVS!");
        pairingStatus = PAIR_PAIRED;
        break;

    case PAIR_REQUEST:
        Serial.print("Pairing request on channel ");
        Serial.println(channel);
        ESP_ERROR_CHECK(esp_wifi_set_channel(channel, WIFI_SECOND_CHAN_NONE));
        if (esp_now_init() != ESP_OK)
        {
            Serial.println("Error initializing ESP-NOW");
        }

        // set callback routines
        esp_now_register_send_cb(OnDataSent);
        esp_now_register_recv_cb(esp_now_recv_cb_t(OnDataRecv));

        // set pairing data to send to the server
        pairingData.msgType = PAIRING;
        pairingData.id = BOARD_ID;
        pairingData.channel = channel;
        memcpy(pairingData.macAddr, clientMacAddress, sizeof(clientMacAddress));

        // add peer and send request
        addPeer(full_mac_address, channel);
        esp_now_send(full_mac_address, (uint8_t *)&pairingData, sizeof(pairingData));
        previousMillis = millis();
        pairingStatus = PAIR_REQUESTED;
        break;

    case PAIR_REQUESTED:
        // time out to allow receiving response from server
        currentMillis = millis();
        if (currentMillis - previousMillis > 1000)
        {
            previousMillis = currentMillis;
            // time out expired,  try next channel
            channel++;
            if (channel > MAX_CHANNEL)
            {
                channel = 1;
                pairing_retry_counter++;
            }
            if (pairing_retry_counter > MAX_RETRY_COUNT)
            {
                Serial.println("esp now pairing time out, enter deep sleep!");
                pairing_retry_counter = 0;
                esp_deep_sleep_start();
            }
            pairingStatus = PAIR_REQUEST;
        }
        break;

    case PAIR_PAIRED:
        // nothing to do here
        break;
    case NOT_PAIRED:
        // nothing to do here
        break;
    }
    return pairingStatus;
}

/**********LED Controller***********/

void update_target_duty(int32_t change_value)
{
    static int32_t led_luminance = 0;
    int32_t change_luminance = change_value * LUMINANCE_CHANGE_WEIGHT;
    led_luminance += change_luminance;

    if (led_luminance < 0)
    {
        led_luminance = 0;
    }
    if (led_luminance > MAX_DUTY)
    {
        led_luminance = MAX_DUTY;
    }

    user_lamp_info.target_duty_ch[0] = led_luminance * user_lamp_info.led_temperature;
    user_lamp_info.target_duty_ch[1] = led_luminance * (1.0f - user_lamp_info.led_temperature);
}

void update_led_temperature(int32_t change_value)
{
    int32_t change_temperature = change_value * TEMPERTURE_CHANGE_WEIGHT;
    static int32_t led_temperature = MAX_TEMPERATURE / 2;

    led_temperature += change_temperature;
    if (led_temperature <= 0)
    {
        led_temperature = 0;
    }
    if (led_temperature >= MAX_TEMPERATURE)
    {
        led_temperature = MAX_TEMPERATURE;
    }

    user_lamp_info.led_temperature = float(led_temperature) / float(MAX_TEMPERATURE); // normalize to [0, 1]
}

AiEsp32RotaryEncoder rotaryEncoder = AiEsp32RotaryEncoder(
    ROTARY_ENCODER_A_PIN,
    ROTARY_ENCODER_B_PIN,
    -1,
    ROTARY_ENCODER_STEPS);

int32_t last_encoder_value = 0;

void ARDUINO_ISR_ATTR readEncoderISR()
{
    rotaryEncoder.readEncoder_ISR();
}

/*custom function*/
bool areMacEqual(const uint8_t mac1[], const uint8_t mac2[], int size)
{
    if (mac1 == nullptr || mac2 == nullptr)
    {
        return false; // 或者根据具体需求选择其他处理方式
    }
    for (int i = 0; i < size; ++i)
    {
        if (mac1[i] != mac2[i])
        {
            return false; // 发现不相等元素，立即返回false
        }
    }
    return true; // 循环结束，所有元素都相等
}

void saveMyPreference(const char *name, const char *key, const void *value, size_t len)
{
    preference.begin(name, false);
    preference.putBytes(key, value, len);
    preference.end();
}

void esp_now_send_data(struct_message my_send_data)
{
    // if (pairingStatus != PAIR_PAIRED)
    // {
    //     Serial.println("ESP NOW not paired, cannot send data!");
    //     return;
    // }
    send_data.command = my_send_data.command;
    send_data.data[0] = my_send_data.data[0];
    send_data.data[1] = my_send_data.data[1];
    esp_err_t result = esp_now_send(serverAddress, (uint8_t *)&send_data, sizeof(send_data));
    if (result != ESP_OK)
    {
        Serial.printf("ESP NOW Send data error, ERR code: 0X%x", result);
    }
}

void led_power_on()
{
    esp_now_send_data(
        {.msgType = DATA,
         .id = BOARD_ID,
         .command = POWER_ON,
         .data = {user_lamp_info.target_duty_ch[0], user_lamp_info.target_duty_ch[1]}});
}
void led_power_off()
{
    esp_now_send_data(
        {.msgType = DATA,
         .id = BOARD_ID,
         .command = POWER_OFF,
         .data = {0, 0}});
}

void on_button_short_click(Button2 &btn)
{
    led_power_on();
    Serial.print("button SHORT press ");
    //   Serial.print(millis());
    //   Serial.println(" milliseconds after restart");
}

void on_button_long_click(Button2 &btn)
{
    led_power_off();
    Serial.print("button LONG press ");
    //   Serial.print(millis());
    //   Serial.println(" milliseconds after restart");
}

void on_button_double_click(Button2 &btn)
{
    Serial.print("button DOUBLE press ");
    //   Serial.print(millis());
    //   Serial.println(" milliseconds after restart");
}

void setup()
{
    Serial.begin(115200);

    // bool format_test = true;
    // if (format_test)
    // {
    //     preference.clear();
    // }

    // // Get peer info from NVS
    // uint8_t zero_mac_addr[6] = {0};
    // preference.begin("my_preference", false);
    // preference.getBytes("peer_info", &peer_info, sizeof(esp_now_peer_info_t));
    // preference.getBytes("user_lamp_info", &user_lamp_info, sizeof(user_lamp_info_t));
    // Serial.print("Get server mac address from NVS is: ");
    // printMAC(peer_info.peer_addr);
    // preference.end();
    // if (areMacEqual(peer_info.peer_addr, zero_mac_addr, sizeof(zero_mac_addr)))
    // {
    //     preference.putBytes("server_mac_addr", serverAddress, sizeof(serverAddress));
    //     pairingStatus = PAIR_REQUEST;
    // }
    // else
    // {
    //     memcpy(serverAddress, peer_info.peer_addr, sizeof(peer_info.peer_addr));
    //     pairingStatus = HAVE_RECORD;
    // }

    // attempt to connect to Wifi network:
    WiFi.mode(WIFI_STA);
    // esp_wifi_set_ps(WIFI_PS_MIN_MODEM);

    // esp_wifi_set_max_tx_power(20);       //1 unit is 0.25dBm, 20 is 5dBm | 3.16mW, default 80| 20dBm
    WiFi.STA.begin();
    // WiFi.disconnect(true); // disconnect from any previous connection

    Serial.print("Client Board MAC Address:  ");
    readGetMacAddress();
    // WiFi.disconnect();

    // esp now initialize
    if (esp_now_init() != ESP_OK)
    {
        Serial.println("Error initializing ESP-NOW");
        return;
    }
    // set callback routines
    esp_now_register_send_cb(OnDataSent);
    esp_now_register_recv_cb(esp_now_recv_cb_t(OnDataRecv));
    Serial.println("ESP NOW init sucessfully!");
    Serial.print("ESP NOW channel is: ");
    Serial.println(channel);

    memcpy(peer_info.peer_addr, serverAddress, sizeof(serverAddress));
    peer_info.channel = 1;
    peer_info.encrypt = false; // not encrypt data
    // addPeer(serverAddress, 4); // add the server to the peer list

    if (esp_now_add_peer(&peer_info) != ESP_OK)
    {
        Serial.println("Failed to add peer");
        pairingStatus = PAIR_REQUEST;
    }
    else
    {
        Serial.println("Peer added successfully");
        pairingStatus = PAIR_PAIRED;
    }

    // // Rotary encoder initialize
    rotaryEncoder.areEncoderPinsPulldownforEsp32 = false;
    rotaryEncoder.begin();
    rotaryEncoder.setup(readEncoderISR);
    rotaryEncoder.setBoundaries(-99999, 99999, false);
    rotaryEncoder.setAcceleration(50);
    last_encoder_value = rotaryEncoder.readEncoder();

    // Encoder button initialize
    encoderButton.begin(ENCODER_BUTTON_PIN, INPUT_PULLUP, true);
    encoderButton.setDebounceTime(50);
    encoderButton.setLongClickTime(2000);
    encoderButton.setDoubleClickTime(300);
    encoderButton.setLongClickDetectedHandler(on_button_long_click);
    encoderButton.setClickHandler(on_button_short_click);
    encoderButton.setDoubleClickHandler(on_button_double_click);

    // // ESP NOW initalize

    start_time = millis();

    // GPIO initalize
    pinMode(LED2_PIN, OUTPUT);

    // set up deep sleep
    uint64_t bitmask = BUTTON_PIN_BITMASK(ROTARY_ENCODER_A_PIN) | BUTTON_PIN_BITMASK(ROTARY_ENCODER_B_PIN);
    esp_deep_sleep_enable_gpio_wakeup(bitmask, ESP_GPIO_WAKEUP_GPIO_LOW);
    // pinMode(ROTARY_ENCODER_A_PIN, INPUT_PULLDOWN);
    // pinMode(ROTARY_ENCODER_B_PIN, INPUT_PULLDOWN);
    gpio_pullup_dis(GPIO_NUM_2);
    gpio_pulldown_en(GPIO_NUM_2);
    gpio_pullup_dis(GPIO_NUM_3);
    gpio_pulldown_en(GPIO_NUM_3);
    // gpio_pullup_dis(GPIO_NUM_4);
    // gpio_pulldown_en(GPIO_NUM_4);

    //
}

static uint32_t one_second_timer = millis();
static uint32_t deep_sleep_check_time = millis();

void loop()
{
    // paring
    // while (autoPairing() != PAIR_PAIRED);

    // if(millis() - one_second_timer >= 1000)
    // {
    //     digitalWrite(LED2_PIN, !digitalRead(LED2_PIN));
    //     one_second_timer = millis();

    // if ((user_lamp_info.current_duty_ch[0] != user_lamp_info.target_duty_ch[0]) ||
    //     (user_lamp_info.current_duty_ch[1] != user_lamp_info.target_duty_ch[1])) {
    //         pairingStatus = PAIR_REQUEST;
    // }
    // }

    // if (millis() - deep_sleep_check_time >= 8000 && pairingStatus == PAIR_PAIRED)
    // {
    //     saveMyPreference("my_preference", "user_lamp_info", &user_lamp_info, sizeof(user_lamp_info_t));
    //     saveMyPreference("my_preference", "peer_info", &peer_info, sizeof(esp_now_peer_info_t));
    //     Serial.println("System into deep light mode, Good bye~");
    //     esp_deep_sleep_start();
    // }

    encoderButton.loop();

    if (rotaryEncoder.encoderChanged())
    {
        deep_sleep_check_time = millis();

        // Serial.println("encoderChanged");
        int32_t encoder_change_value = rotaryEncoder.readEncoder() - last_encoder_value;
        Serial.printf("Encoder change value: %ld\n", encoder_change_value);
        rotary_direction = encoder_change_value > 0 ? 1 : -1; // CW: 1, ACW: -1
        last_encoder_value = rotaryEncoder.readEncoder();
        //        rotaryEncoder.setEncoderValue(0); // reset encoder value to 0 after reading

        if (encoderButton.isPressed())
        {
            Serial.println("Encoder button pressed");
            update_led_temperature(encoder_change_value);
            update_target_duty(0);
        }
        else
        {
            update_target_duty(encoder_change_value);
        }

        Serial.printf("Current duty ch1: %ld, ch2: %ld\n",
                      user_lamp_info.current_duty_ch[0],
                      user_lamp_info.current_duty_ch[1]);
        Serial.printf("Target duty ch1: %ld, ch2: %ld, temperature: %.2f\n",
                      user_lamp_info.target_duty_ch[0],
                      user_lamp_info.target_duty_ch[1],
                      user_lamp_info.led_temperature);

        if ((user_lamp_info.target_duty_ch[0] != user_lamp_info.current_duty_ch[0]) || (user_lamp_info.target_duty_ch[1] != user_lamp_info.current_duty_ch[1]))
        {
            esp_now_send_data({.msgType = DATA,
                               .id = BOARD_ID,
                               .command = SET_DUTY,
                               .data = {user_lamp_info.target_duty_ch[0], user_lamp_info.target_duty_ch[1]}});

            Serial.printf("Send data: SET_DUTY, ch1: %ld, ch2: %ld\n",
                          user_lamp_info.target_duty_ch[0],
                          user_lamp_info.target_duty_ch[1]);
        }
    }

    // for (int i = 1; i < 13; i++)
    // {
    //     // peer_info.channel = i;
    //     addPeer(serverAddress, i); // add the server to the peer list
    //     esp_now_send_data({.msgType = DATA,
    //                        .id = BOARD_ID,
    //                        .command = SET_DUTY,
    //                        .data = {user_lamp_info.target_duty_ch[0], user_lamp_info.target_duty_ch[1]}});

    //     delay(1000); // wait for 1 second before next iteration
    // }
}

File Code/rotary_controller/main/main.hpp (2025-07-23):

#pragma once

#include "AiEsp32RotaryEncoder.h"
#include "Button2.h"
#include <WiFi.h>
#include <esp_wifi.h>
#include <esp_now.h>
#include <cmath>
#include <driver/rtc_io.h>
#include <Preferences.h>


#define ROTARY_ENCODER_A_PIN 2
#define ROTARY_ENCODER_B_PIN 3
#define ROTARY_ENCODER_STEPS 4


#define ENCODER_BUTTON_PIN 4
#define BTN_DEBOUNCE_MS 50
#define BTN_LONGCLICK_MS 200
#define BTN_DOUBLECLICK_MS 300

#define LED2_PIN 5

#define PWM_RES 9    
#define MAX_RETRY_COUNT 3
#define TEMPERTURE_CHANGE_WEIGHT 5
#define LUMINANCE_CHANGE_WEIGHT 1

#define BUTTON_PIN_BITMASK(GPIO) (1ULL << GPIO) 

enum LedState
{
    LED_POWER_OFF = 0,
    LED_POWER_ON = 1,
};
LedState ledState = LED_POWER_OFF;


/**********ESP NOW********* */
#define BOARD_ID 1
#define MAX_CHANNEL 13 // 11 in North America or 13 in China

unsigned long currentMillis = millis();
unsigned long previousMillis = 0; // Stores last time temperature was published
const long interval = 10000;      // Interval at which to publish sensor readings
unsigned long start_time = 0;              // used to measure Pairing time
unsigned int readingId = 0;

uint8_t serverAddress[] = {0x80, 0x64, 0x6f, 0x41, 0x5d, 0x5c};
uint8_t full_mac_address[] = {0xFF, 0xFF, 0xFF, 0xFF, 0xFF, 0xFF};
uint8_t clientMacAddress[6];

int16_t rotary_direction;


enum MessageType
{
    PAIRING,
    DATA,
};
MessageType messageType;

enum PairingStatus
{
    NOT_PAIRED,
    PAIR_REQUEST,
    PAIR_REQUESTED,
    PAIR_PAIRED,
    HAVE_RECORD,
};
PairingStatus pairingStatus = PAIR_REQUEST;

enum MessageCommand
{
    SET_DUTY,
    SET_TEMPERATURE,
    RESPONSE_SET_DUTY,
    POWER_ON,
    POWER_OFF,
};
MessageCommand Messagecommand;

uint16_t counter = 0;

// Set received data structure
struct struct_message
{
    uint8_t msgType;
    uint8_t id;
    MessageCommand command;
    int32_t data[2];
};

// set pairing structure
struct struct_pairing
{
    uint8_t msgType;
    uint8_t id;
    uint8_t macAddr[6];
    uint8_t channel;
};

esp_now_peer_info_t peer_info;

struct_message myData;  // data to send
struct_message inData;  // data received
struct_pairing pairingData;

#ifdef SAVE_CHANNEL
int lastChannel;
#endif
int channel = 0;


uint16_t pairing_retry_counter = 0;
uint16_t server_board_id = 10;

void saveMyPreference(const char* name, const char* key, const void* value, size_t len);

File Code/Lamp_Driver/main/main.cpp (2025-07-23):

#include "Arduino.h"
#include "main.hpp"

Preferences preference;

int32_t target_duty_ch[2] = {50, 50};
int32_t current_duty_ch[2] = {0, 0};
int32_t current_temperture = 4000;
const int32_t MAX_DUTY = pow(2, PWM_RES); // Max num: 512
const int32_t MINIMUM_DUTY = 10;          // Max num: 512

void init_led_driver()
{
    if (!ledcSetClockSource(LEDC_USE_XTAL_CLK))
    {
        Serial.println("LEDC set clock error!");
        return;
    }
    ledcAttach(LED_CH0_PIN, PWM_FREQ, PWM_RES);
    ledcAttach(LED_CH1_PIN, PWM_FREQ, PWM_RES);

    ledcWrite(LED_CH0_PIN, 0);
    ledcWrite(LED_CH1_PIN, 0);
}

void led_set_duty(int32_t *target_duty_array)
{
    Serial.print("set duty ch0 ch1: ");
    Serial.println(target_duty_array[0]);
    Serial.println(target_duty_array[1]);
    int32_t* max_duty_pt = target_duty_array[0] >= target_duty_array[1] ? &target_duty_array[0] : &target_duty_array[1];
    int32_t* minimum_duty_pt = target_duty_array[0] <= target_duty_array[1] ? &target_duty_array[0] : &target_duty_array[1];

    // Duty range limit
    if(*max_duty_pt > MAX_DUTY) {
        *max_duty_pt = MAX_DUTY;
    }
    if(*minimum_duty_pt < MINIMUM_DUTY) {
        *minimum_duty_pt = 0;
    }

    // LED CH0 5000k
    ledcFade(
        LED_CH0_PIN,
        uint32_t(current_duty_ch[0]),
        uint32_t(target_duty_array[0]),
        abs(target_duty_array[0]-current_duty_ch[0]) * LED_STEP_FADE_TIME_MS
    );
    // LED CH1 2700k
    ledcFade(
        LED_CH1_PIN,
        uint32_t(current_duty_ch[1]),
        uint32_t(target_duty_array[1]),
        abs(target_duty_array[1]-current_duty_ch[1]) * LED_STEP_FADE_TIME_MS
    );
    current_duty_ch[0] = target_duty_array[0];
    current_duty_ch[1] = target_duty_array[1];
}

inline void led_change_intensity_by_step(int32_t step_duty)
{
    int32_t target_duty_array[2] = {current_duty_ch[0] + step_duty, current_duty_ch[1] + step_duty};
    led_set_duty(target_duty_array);
}

inline void led_change_temperature(int32_t step_duty)
{
    int32_t target_duty_array[2] = {current_duty_ch[0] + step_duty, current_duty_ch[1] - step_duty};
    led_set_duty(target_duty_array);
}

inline void led_power_off()
{
    ledcFade(
        LED_CH0_PIN,
        uint32_t(current_duty_ch[0]),
        0,
        LED_POWER_ON_OFF_FADE_TIME_MS);
    // LED CH1 2700k
    ledcFade(
        LED_CH1_PIN,
        uint32_t(current_duty_ch[1]),
        0,
        LED_POWER_ON_OFF_FADE_TIME_MS);
}

inline void led_power_on()
{
    ledcFade(
        LED_CH0_PIN,
        0,
        uint32_t(current_duty_ch[0]),
        LED_POWER_ON_OFF_FADE_TIME_MS);
    // LED CH1 2700k
    ledcFade(
        LED_CH1_PIN,
        0,
        uint32_t(current_duty_ch[1]),
        LED_POWER_ON_OFF_FADE_TIME_MS);
}

/*********************ESP NOW**************************/
void readMacAddress()
{
    uint8_t baseMac[6];
    esp_err_t ret = esp_wifi_get_mac(WIFI_IF_STA, baseMac);
    if (ret == ESP_OK)
    {
        Serial.printf("%02x:%02x:%02x:%02x:%02x:%02x\n",
                      baseMac[0], baseMac[1], baseMac[2],
                      baseMac[3], baseMac[4], baseMac[5]);
    }
    else
    {
        Serial.println("Failed to read MAC address");
    }
}

void printMAC(const uint8_t *mac_addr)
{
    char macStr[18];
    snprintf(macStr, sizeof(macStr), "%02x:%02x:%02x:%02x:%02x:%02x",
             mac_addr[0], mac_addr[1], mac_addr[2], mac_addr[3], mac_addr[4], mac_addr[5]);
    Serial.print(macStr);
}

bool addPeer(const uint8_t *peer_addr)
{
    memset(&slave, 0, sizeof(slave));
    const esp_now_peer_info_t *peer = &slave;
    memcpy(slave.peer_addr, peer_addr, 6);

    // slave.channel = channel; // pick a channel
    slave.channel = 4;
    slave.encrypt = false;       // no encryption

    // check if the peer exists
    bool exists = esp_now_is_peer_exist(slave.peer_addr);
    if (exists)
    {
        // Slave already paired.
        Serial.println("Already Paired");
        return true;
    }
    else
    {
        esp_err_t addStatus = esp_now_add_peer(peer);
        if (addStatus == ESP_OK)
        {
            // Pair success
            Serial.println("Pair success");
            return true;
        }
        else
        {
            Serial.println("Pair failed");
            return false;
        }
    }
}

// callback when data is sent
void OnDataSent(const uint8_t *mac_addr, esp_now_send_status_t status)
{
    Serial.print("Last Packet Send Status: ");
    Serial.print(status == ESP_NOW_SEND_SUCCESS ? "Delivery Success to " : "Delivery Fail to ");
    printMAC(mac_addr);
    Serial.println();
}

void OnDataRecv(const uint8_t *mac_addr, const uint8_t *incomingData, int len)
{
    Serial.print(len);
    Serial.println(" bytes of new data received.");
    MessageType type = MessageType(incomingData[0]); // first message byte is the type of message
    switch (type)
    {
        case DATA: // the message is data type
        {
            memcpy(&incomingReadings, incomingData, sizeof(incomingReadings));
            if (incomingReadings.command == SET_DUTY)
            {
                led_set_duty(incomingReadings.data);
            }
            else if (incomingReadings.command == POWER_OFF)
            
            {
                led_power_off();
            }
            else if (incomingReadings.command == POWER_ON)
            {
                led_power_on();
            }

            outgoingSetpoints.msgType = DATA;
            outgoingSetpoints.id = BOARD_ID;
            outgoingSetpoints.command = incomingReadings.command;
            outgoingSetpoints.data[0] = current_duty_ch[0];
            outgoingSetpoints.data[1] = current_duty_ch[1];

            esp_err_t result = esp_now_send(clientMacAddress, (uint8_t *) &outgoingSetpoints, sizeof(outgoingSetpoints));
            if (result != ESP_OK) {
                Serial.printf("Send data fault, Error code: 0X%x", result);
            }
            break;  
        }
        case PAIRING:// the message is a pairing request
        {
            memcpy(&pairingData, incomingData, sizeof(pairingData));
            Serial.println(pairingData.msgType);
            Serial.println(pairingData.id);
            Serial.print("Pairing request from MAC Address: ");
            printMAC(pairingData.macAddr);
            Serial.print(" on channel ");
            Serial.println(pairingData.channel);

            memcpy(clientMacAddress, pairingData.macAddr, sizeof(clientMacAddress));
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

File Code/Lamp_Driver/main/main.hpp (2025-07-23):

#pragma once


#include <esp_now.h>
#include <WiFi.h>
#include <esp_wifi.h>
#include <cmath>
#include <Preferences.h>



/*********LED Driver*********/
#define LED_CH0_PIN 0 // 5000k
#define LED_CH1_PIN 1 // 2700k
#define PWM_RES 9
#define PWM_FREQ 20000

#define LED_STEP_FADE_TIME_MS 3
#define LED_POWER_ON_OFF_FADE_TIME_MS 2000

#define MAX_TEMPERTURE 5000
#define MINIMUM_TEMPERTURE 2700


/*********************ESP NOW**************************/
#define BOARD_ID 10
esp_now_peer_info_t slave;
uint8_t channel;

enum MessageType
{
    PAIRING,
    DATA,
};
MessageType messageType;

enum MessageCommand
{
    SET_DUTY,
    SET_TEMPERATURE,
    RESPONSE_SET_DUTY,
    POWER_ON,
    POWER_OFF,
};
MessageCommand Messagecommand;

uint16_t counter = 0;
uint8_t clientMacAddress[6] = {0x50, 0x40, 0x6f, 0x40, 0xba, 0x18};

// Set received data structure
struct struct_message
{
    uint8_t msgType;
    uint8_t id;
    MessageCommand command;
    int32_t data[2];
};

// set pairing structure
struct struct_pairing
{
    uint8_t msgType;
    uint8_t id;
    uint8_t macAddr[6];
    uint8_t channel;
};

struct_message incomingReadings;
struct_message outgoingSetpoints;
struct_pairing pairingData;

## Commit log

2025-07-23 首次提交
    [BOM_Base_Board_2025-07-23.xlsx, BOM_Driver Board _2025-07-23.xlsx, BOM_Rotary_Controller_Board_2025-07-23.xlsx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]
2025-07-25 Add Reference floder
    [BOM_LGS6304X ESOP8 降压 (送样)_2023-07-26.csv, BOM_PCB_LGS6304X ESOP8 Buck_Boost copy（送样30片）_2023-07-26.csv, BOM_PCB_LGS6304X ESOP8 升压 （送样）_2023-07-26.csv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]
2025-07-25 Add screw selection
2025-08-08 update BOM D2 D3 D4
    [BOM_Driver Board _2025-07-23.xlsx]

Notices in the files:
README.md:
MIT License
